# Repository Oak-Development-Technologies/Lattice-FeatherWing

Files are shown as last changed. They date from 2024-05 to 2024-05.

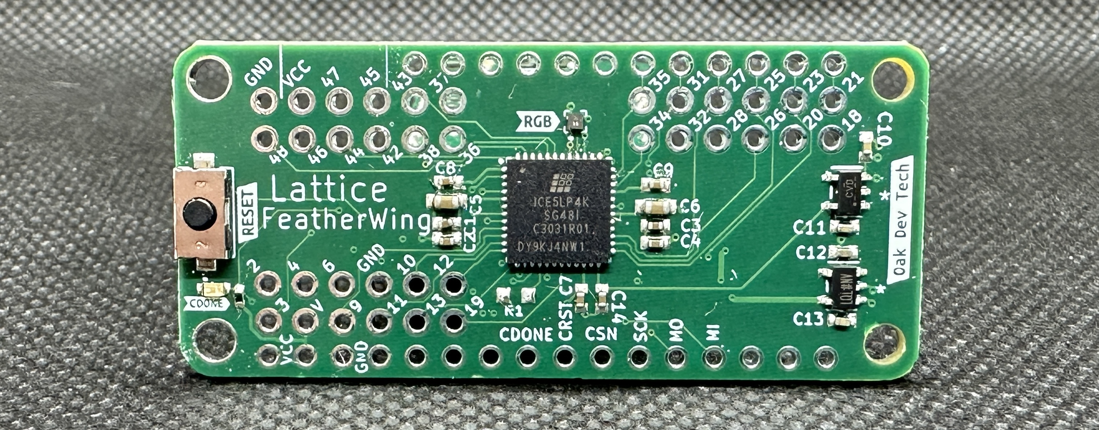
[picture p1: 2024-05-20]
images/lattice featherwing front.jpg

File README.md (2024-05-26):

# Lattice FeatherWing
<image src=/images/lattice%20featherwing%20front.jpg>
Home of the Lattice FeatherWing

Lattice FeatherWing is an iCE5LP4K FeatherWing designed to be a companion to any Adafruit compatible feather development board available. Lattice FeatherWing provides 35 IO to 0.1" headers which can be used with dupont 0.1" cables to hook into a companion breadboard.

Interested? You can purchase the Lattice FeatherWing on [Tindie](https://www.tindie.com/products/34549/)

# Quick Facts about Lattice FeatherWing:

* 35 IO Exposed to 0.1" headers 
* 9 IO (including SPI programming pins) directly available to interface with host Feather.
* Small yet bright UHD1110 RGB LED
* 2.5V provided for NVCM programming
* Edge reachable reset button that solely resets the FPGA

# Pinout Card

Provided below is the pinout card that should ship with all Lattice FeatherWing. If you didn't get one, you can always print off the pinout card from the pinout card image in the [images](/images) directory of this repository.

<image src=/images/Lattice%20FeatherWing%20Pincard.jpg>

As noted on the pinout card, each pin on the Lattice FeatherWing corresponds to the phyiscal pin on the FPGA IC. These phyiscal pins are used in the [io.pcf](/examples/common/io.pcf) file to help make it easier for you to pick pins for input/outputs of your verilog designs. These pin numbers can be used to create pin groupings like in the io.pcf file to make it easier to generate your own designs.

# Some Quick Links

You can find some Lattice FeatherWing specific examples by clicking [here](/examples). These examples can be built with the included io.pcf and Makefile by using various make commands. (currently just RGB PWM example available).

In addition to the examples in this repository, you can also find examples for the iCE5LP4K in this [ice5lp4k_examples repository](https://github.com/skerr92/ice5lp4k_examples).

If you're interested in CPU design, you can checkout the [O2 Trainer CPU](https://github.com/skerr92/O2-Trainer).

The KiCAD board files and manufacturing files can be found by clicking [here](/Board%20Files/). These include all the information you need to make your own Lattice FPGA board, or order the files yourself if you want the challenge of making your own.

Lattice FeatherWing is Licensed under [MIT License](LICENSE). This license is permissive, and the contents of this repository come AS IS. Please see the License file for additonal details.

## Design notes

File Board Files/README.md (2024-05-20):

Find relevant schematic and board files here.

These are the latest revision available, you can open them directly in kicad.

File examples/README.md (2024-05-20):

# Verilog Examples for thek Lattice FeatherWing

All examples can be built by modifying the `top.v` file. By default, it builds the RGB pwm example.

to build follwo the next steps:
1. run `make build` (make sure to have the OSS CAD Suite installed)

You can program this directly using the `make prog` command using an FT232H like ones sold by Adafruit.

Additionally, you can use [IcePython](https://github.com/skerr92/Oakdevtech_CircuitPython_IcePython) to program the FPGA via circuitpython.

More examples are coming in the future. If you wish to try other examples, checkout this [ice5lp4k examples library](https://github.com/skerr92/ice5lp4k_examples).

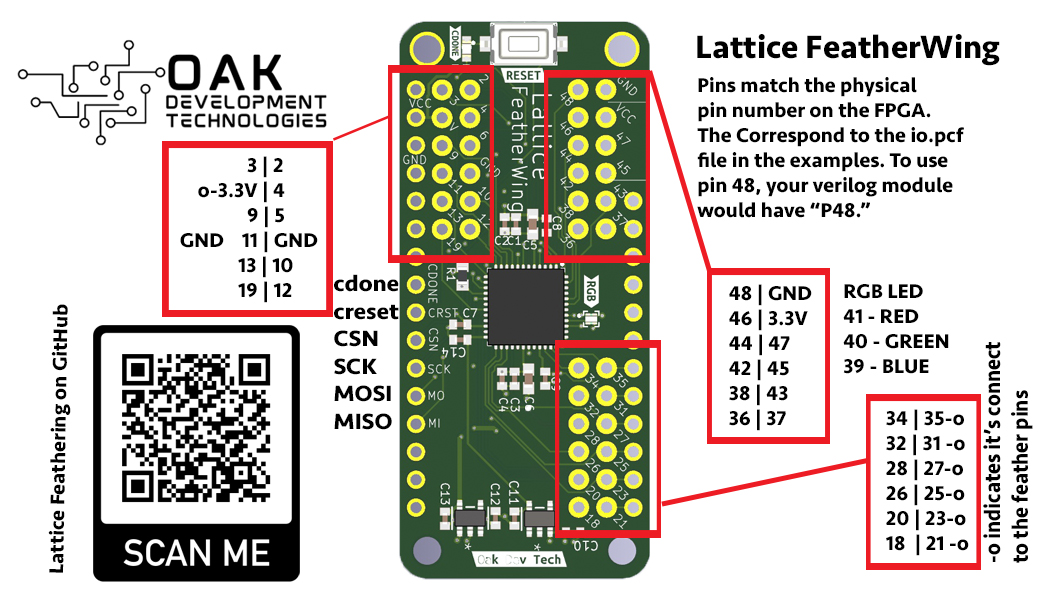
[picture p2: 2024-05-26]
images/Lattice FeatherWing Pincard.jpg

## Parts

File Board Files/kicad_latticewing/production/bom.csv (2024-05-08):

Designator | Footprint | Quantity | Value | LCSC Part #
C1, C14, C2, C3, C4, C7, C8, C9 | C0402 | 8 | 0.1uF
C10, C11, C12 | C0402 | 3 | 1uF
C13 | C0402 | 1 | 0.47uF
C5, C6 | C0603 | 2 | 4.7uF
CDONE0 | CHIP-LED0603 | 1 | LEDCHIP-LED0603
J3, J4, J5 | 2X6_NOSILK | 3 | 2X6 FEMALE
R1 | R0603 | 1 | 10k
R2 | R0402 | 1 | 10k
RGB0 | LED_UHD1110-FKA-CL1A13R3Q1BBQFMF3 | 1 | UHD1110-FKA-CL1A13R3Q1BBQFMF3
S1 | SW_KSR223GLFG | 1 | KSR223GLFG
U$1 | FEATHER_PINS | 1 | FEATHER_BASE
U1 | QFN50P700X700X100-49N | 1 | ICE5LP1K-SG48ITR
U2, U3 | DBV5_TEX-L | 2 | TLV75533PDBVRDBV5_TEX-L

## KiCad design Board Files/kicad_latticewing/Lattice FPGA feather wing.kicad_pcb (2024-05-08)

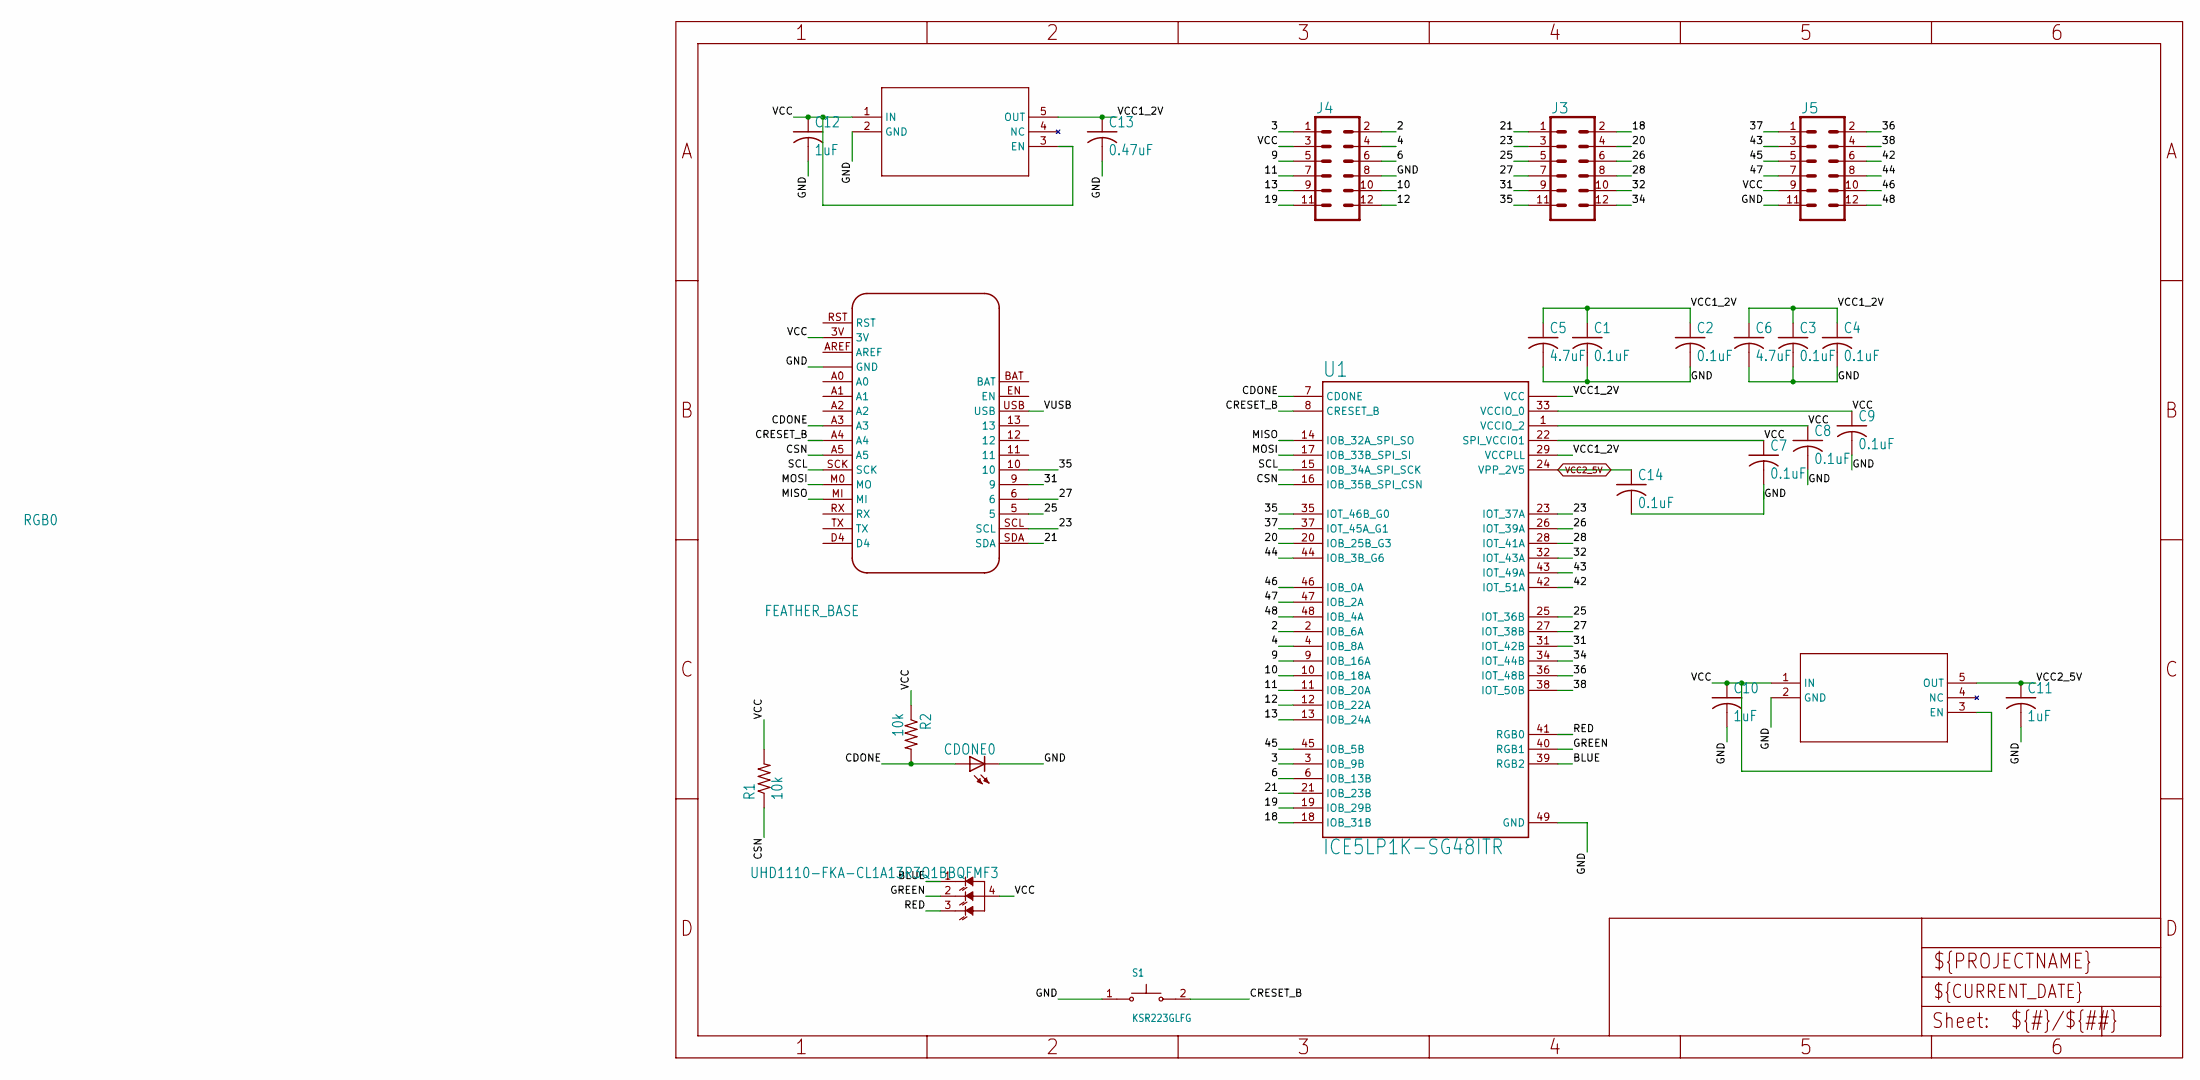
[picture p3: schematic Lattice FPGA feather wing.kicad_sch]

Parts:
C1, C2, C3, C4, C7, C8, C9, C14: 0.1uF; C0402
C5, C6: 4.7uF; C0603
C10, C11, C12: 1uF; C0402
C13: 0.47uF; C0402
CDONE0: LEDCHIP-LED0603; CHIP-LED0603
J3, J4, J5: 2X6 FEMALE; 2X6_NOSILK
R1: 10k; R0603
R2: 10k; R0402
RGB0: UHD1110-FKA-CL1A13R3Q1BBQFMF3; LED_UHD1110-FKA-CL1A13R3Q1BBQFMF3
S1: KSR223GLFG; SW_KSR223GLFG
U1: ICE5LP1K-SG48ITR; QFN50P700X700X100-49N
U2, U3: TLV75533PDBVRDBV5_TEX-L; DBV5_TEX-L
U$1: FEATHER_BASE; FEATHER_PINS

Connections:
/2: J4.2, U1.2 (IOB_6A)
/3: J4.1, U1.3 (IOB_9B)
/4: J4.4, U1.4 (IOB_8A)
/6: J4.6, U1.6 (IOB_13B)
/9: J4.5, U1.9 (IOB_16A)
/10: J4.10, U1.10 (IOB_18A)
/11: J4.7, U1.11 (IOB_20A)
/12: J4.12, U1.12 (IOB_22A)
/13: J4.9, U1.13 (IOB_24A)
/18: J3.2, U1.18 (IOB_31B)
/19: J4.11, U1.19 (IOB_29B)
/20: J3.4, U1.20 (IOB_25B_G3)
/21: J3.1, U1.21 (IOB_23B), U$1.SDA
/23: J3.3, U1.23 (IOT_37A), U$1.SCL
/25: J3.5, U1.25 (IOT_36B), U$1.5
/26: J3.6, U1.26 (IOT_39A)
/27: J3.7, U1.27 (IOT_38B), U$1.6
/28: J3.8, U1.28 (IOT_41A)
/31: J3.9, U1.31 (IOT_42B), U$1.9
/32: J3.10, U1.32 (IOT_43A)
/34: J3.12, U1.34 (IOT_44B)
/35: J3.11, U1.35 (IOT_46B_G0), U$1.10
/36: J5.2, U1.36 (IOT_48B)
/37: J5.1, U1.37 (IOT_45A_G1)
/38: J5.4, U1.38 (IOT_50B)
/42: J5.6, U1.42 (IOT_51A)
/43: J5.3, U1.43 (IOT_49A)
/44: J5.8, U1.44 (IOB_3B_G6)
/45: J5.5, U1.45 (IOB_5B)
/46: J5.10, U1.46 (IOB_0A)
/47: J5.7, U1.47 (IOB_2A)
/48: J5.12, U1.48 (IOB_4A)
/BLUE: RGB0.1 (BLUE), U1.39 (RGB2)
/CDONE: CDONE0.A, R2.2, U1.7 (CDONE), U$1.A3
/CRESET_B: S1.2, U1.8 (CRESET_B), U$1.A4
/CSN: R1.1, U1.16 (IOB_35B_SPI_CSN), U$1.A5
/GND: C1.2, C2.2, C3.2, C4.2, C5.2, C6.2, C7.2, C8.2, C9.2, C10.2, C11.2, C12.2, C13.2, C14.2, CDONE0.C, J4.8, J5.11, S1.1, U1.49 (GND), U2.2 (GND), U3.2 (GND), U$1.GND, U$1.P$1 (GND), U$1.P$2 (GND)
/GREEN: RGB0.2 (GREEN), U1.40 (RGB1)
/MISO: U1.14 (IOB_32A_SPI_SO), U$1.MI
/MOSI: U1.17 (IOB_33B_SPI_SI), U$1.M0 (MO)
/RED: RGB0.3 (RED), U1.41 (RGB0)
/SCL: U1.15 (IOB_34A_SPI_SCK), U$1.SCK
/VCC: C7.1, C8.1, C9.1, C10.1, C12.1, J4.3, J5.9, R1.2, R2.1, RGB0.4 (ANODE), U1.1 (VCCIO_2), U1.22 (SPI_VCCIO1), U1.33 (VCCIO_0), U2.1 (IN), U2.3 (EN), U3.1 (IN), U3.3 (EN), U$1.3V
/VCC1_2V: C1.1, C2.1, C3.1, C4.1, C5.1, C6.1, C13.1, U1.5 (VCC), U1.29 (VCCPLL), U1.30 (VCC), U2.5 (OUT)
/VUSB: U$1.USB
VCC2_5V: C11.1, C14.1, U1.24 (VPP_2V5), U3.5 (OUT)

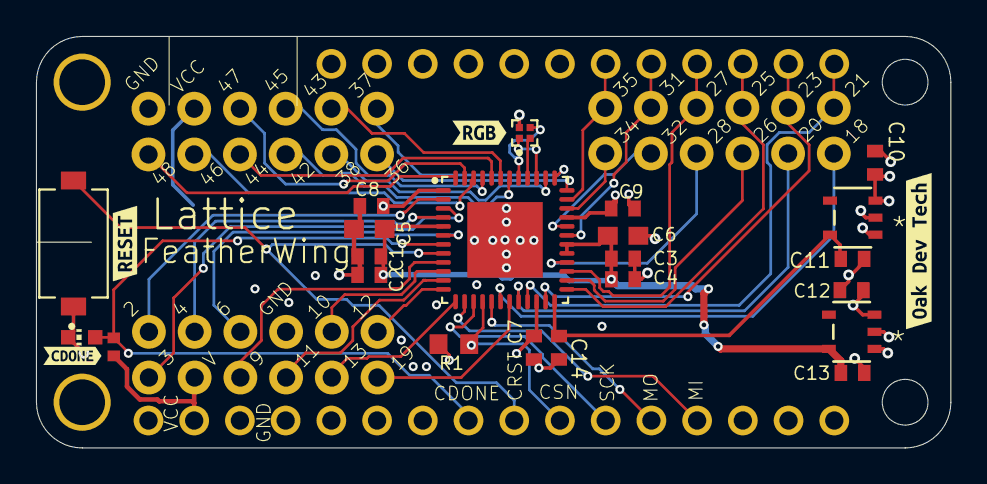
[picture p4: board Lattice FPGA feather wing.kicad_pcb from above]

Board: 4 copper layers, 50.8 x 22.9 mm, 30 parts (0 on the bottom side), 45 nets.

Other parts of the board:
kibuzzard-661C746D: G***; kibuzzard-661C746D
kibuzzard-661C7431: G***; kibuzzard-661C7431
kibuzzard-661C7456: G***; kibuzzard-661C7456
kibuzzard-662D2453: G***; kibuzzard-662D2453

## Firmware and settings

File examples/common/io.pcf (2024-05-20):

# pin definitions for lattice featherwing

set_io LED_R 41
set_io LED_G 40
set_io LED_B 39
set_io LED2 2
set_io LED3 3

set_io RGB[2] 41
set_io RGB[1] 40
set_io RGB[0] 39

set_io reset 4

set_io BUS8[0] 37
set_io BUS8[1] 38
set_io BUS8[2] 42
set_io BUS8[3] 43
set_io BUS8[4] 44
set_io BUS8[5] 45
set_io BUS8[6] 46
set_io BUS8[7] 47

set_io MUX3[0] 9
set_io MUX3[1] 10
set_io MUX3[2] 11

#GPIO
set_io P2 2
set_io P2 3
set_io P4 4
set_io P6 6
set_io P9 9
set_io P10 10
set_io P11 11
set_io P12 12
set_io P13 13
set_io P18 18
set_io P19 19
set_io P20 20
set_io P21 21
set_io P23 23
set_io P25 25
set_io P26 26
set_io P27 27
set_io P28 28
set_io P31 31
set_io P32 32
set_io P34 34
set_io P35 35
set_io P37 37
set_io P38 38
set_io P42 42
set_io P43 43
set_io P44 44
set_io P45 45
set_io P46 46
set_io P47 47
set_io P48 48

#spi
set_io SPI_SS 16
set_io SPI_SCK 15
set_io SPI_MOSI 17
set_io SPI_MISO 14

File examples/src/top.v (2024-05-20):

`include "pwm.v"
module top(output [2:0] RGB);
    reg [18:0] counter;
    reg [7:0] val_pwm0; //only make it go to 128 (half brightness)
    reg [7:0] val_pwm1; //only make it go to 128 (half brightness)
    reg [7:0] val_pwm2; //only make it go to 128 (half brightness)

    wire pwm_en_bit;
    wire clk;

    reg [2:0] leds;
    reg [7:0] val_in0;
    reg [7:0] val_in1;
    reg [7:0] val_in2;

    SB_HFOSC SB_HFOSC_inst(
      .CLKHFEN(1),
      .CLKHFPU(1),
      .CLKHF(clk)
    );

    pwm pwm_init(.clk(clk),
                 .en(pwm_en_bit),
                 .value_input0(val_in0),
                 .value_input1(val_in1),
                 .value_input2(val_in2),
                 .out(leds));

    assign RGB = ~leds;

    initial begin
        counter = 0;
        pwm_en_bit = 1;
        val_pwm0 = 255;
        val_pwm1 = 0;
        val_pwm2 = 0;
    end

    always @(posedge clk)
    begin
    
        pwm_en_bit = 0;
        counter <= counter + 1;
    
        if(counter == 0) begin
            if (val_pwm0 > 0 && val_pwm1 < 255 && val_pwm2 == 0) begin
                val_pwm0 <= val_pwm0 - 1; //increase the width of pwm
                val_pwm1 <= val_pwm1 + 1;
            end
            if (val_pwm0 == 0 && val_pwm1 > 0 && val_pwm2 < 255) begin
                val_pwm1 <= val_pwm1 - 1; //increase the width of pwm
                val_pwm2 <= val_pwm2 + 1;
            end
            if (val_pwm0 < 255 && val_pwm1 == 0 && val_pwm2 > 0) begin
                val_pwm2 <= val_pwm2 - 1; //increase the width of pwm
                val_pwm0 <= val_pwm0 + 1;
            end

            pwm_en_bit = 1;
            val_in0 <= val_pwm0;
            val_in1 <= val_pwm1;
            val_in2 <= val_pwm2;
        end
    end
endmodule
